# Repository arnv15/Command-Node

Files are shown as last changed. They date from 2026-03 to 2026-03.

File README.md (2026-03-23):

# Command Node

A fully custom 3D printed macropad built from scratch with a 3×3 key grid, rotary encoder, and OLED display.

## Features

- 9x Cherry MX switches in a 3×3 layout
- EC11 rotary encoder (volume control + OS toggle click)
- 0.91" 128×32 SSD1306 OLED display showing name and current OS layer
- Dual OS support — toggle between Windows and Mac layouts instantly
- KMK firmware written in CircuitPython (no compiling needed!)
- 3D printed case with heat-set inserts
- Seeed XIAO RP2040 microcontroller

## Overall Design

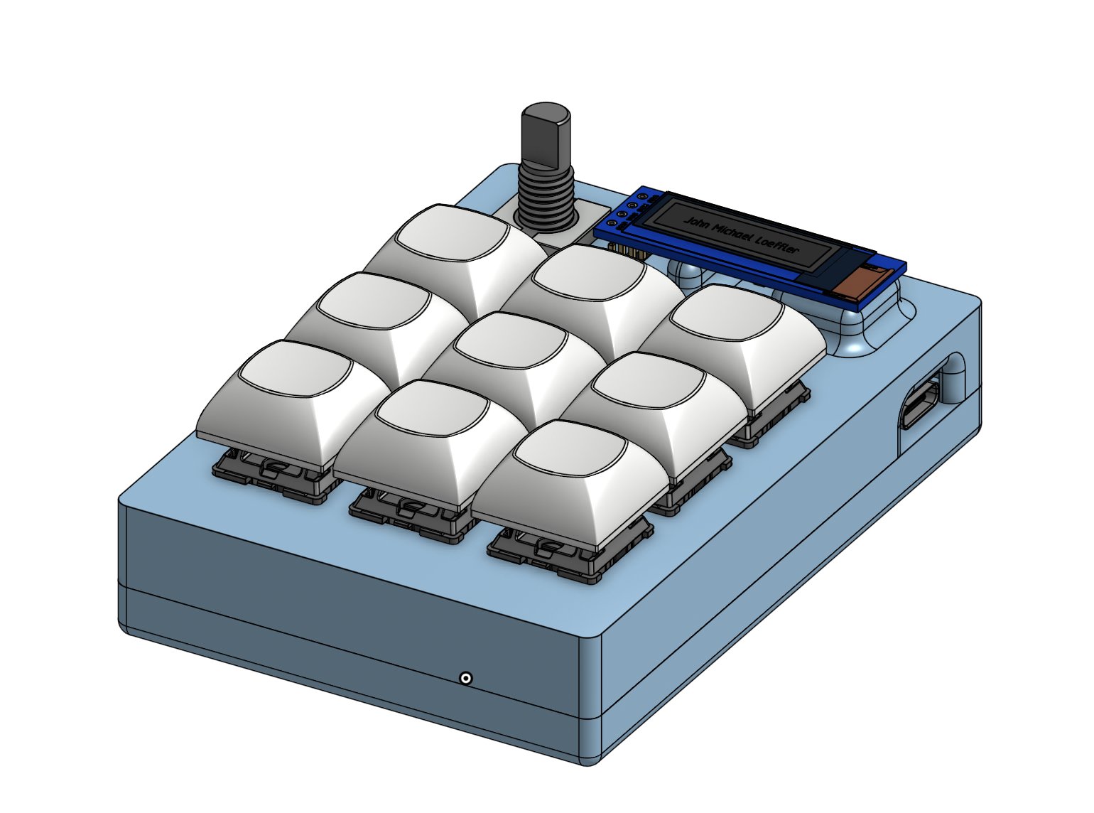
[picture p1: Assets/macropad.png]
Macropad render


The macropad features a compact 3×3 key layout with the rotary encoder and OLED display across the top. The USB-C port is accessible from the right side. The two-part 3D printed case is held together with M3 screws and heat-set inserts.

## PCB

| **Schematic** | **PCB Layout** |
| --- | --- |
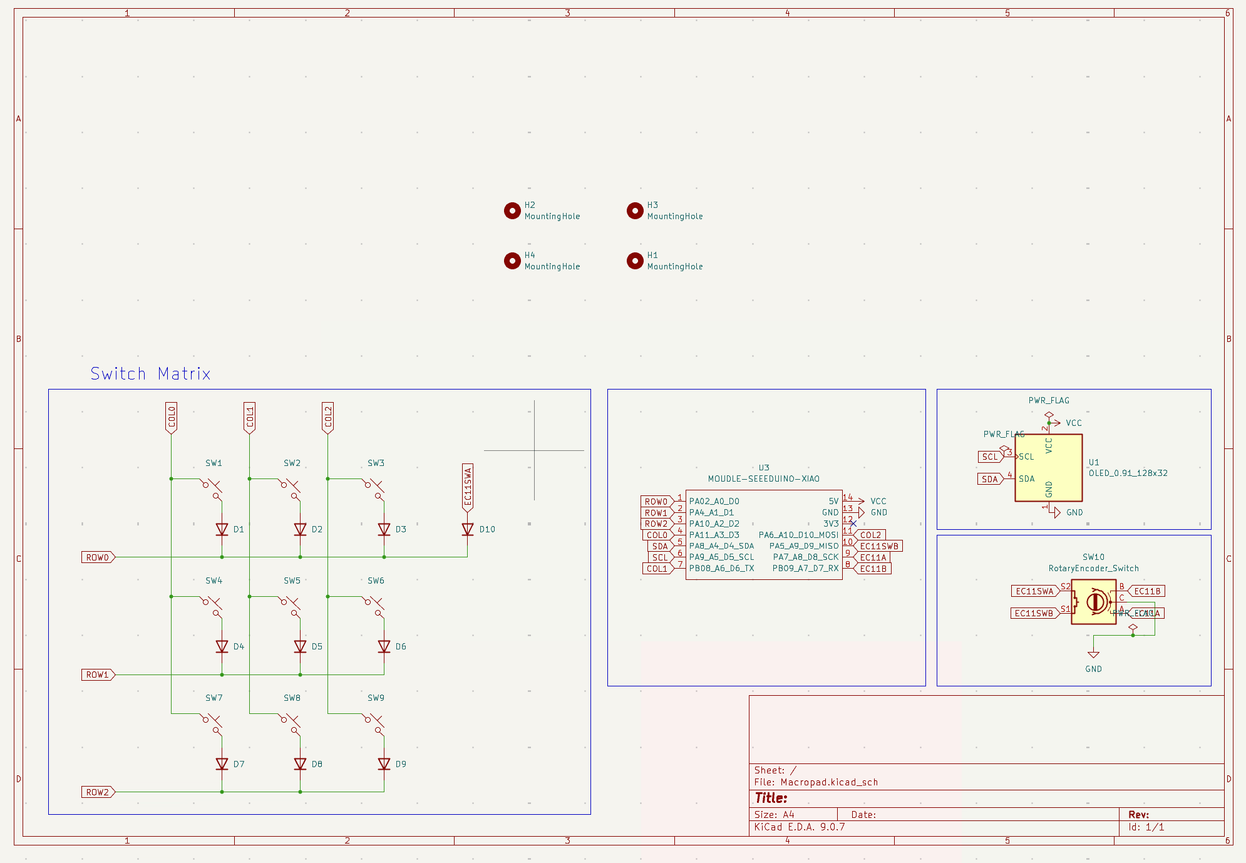
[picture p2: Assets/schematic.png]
Schematic
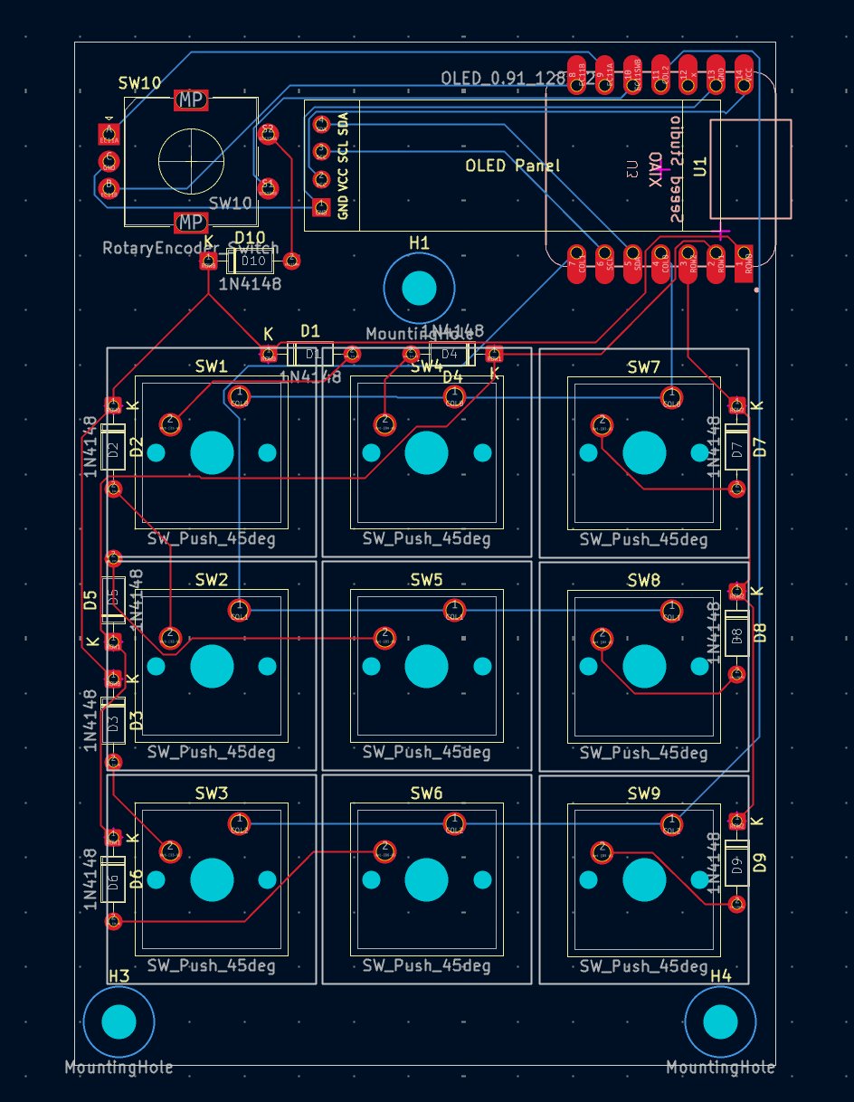
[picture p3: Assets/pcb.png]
PCB
|  |  |

The PCB was designed in KiCad. The switch matrix uses COL2ROW diode direction with 1N4148 diodes. The OLED connects via I2C on SDA/SCL pins, and the EC11 encoder click is wired as a direct pin (no diode needed).

- [x] I ran DRC and there are 0 errors

## CAD

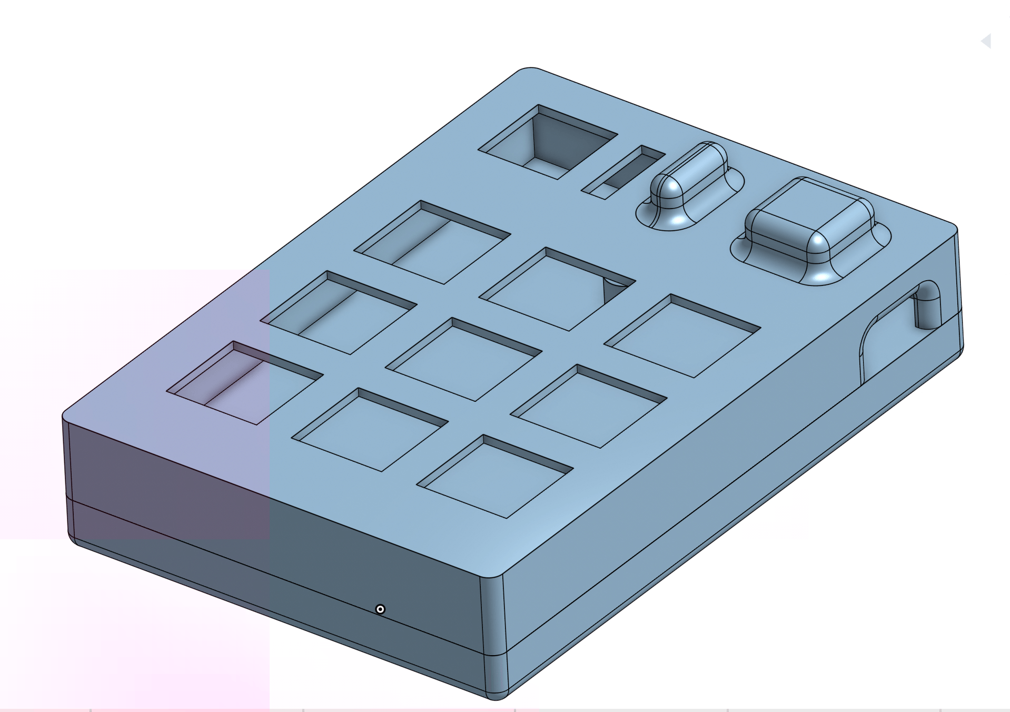
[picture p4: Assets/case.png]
Case assembly


The case is two-part and 3D printed. The top shell holds the switches, encoder, and OLED in place, while the bottom shell houses the PCB. Everything is secured with 4x M3x16mm screws threading into M3x5x4mm heat-set inserts pressed into the bottom shell.

[OnShape Link](https://cad.onshape.com/documents/35dce9458257a454ca9a87ec/w/10d574b05dc610b688c542cb/e/8b960576cf94807eaae72969)

## Firmware

Written using **KMK** (CircuitPython) — no compiling or flashing needed after the initial CircuitPython setup. Just edit `code.py` on the `CIRCUITPY` drive and it reloads automatically.

**Key layout:**

```
[ Prev  ] [ Play  ] [ Next  ]
[ Ctrl+Z] [ Ctrl+C] [ Ctrl+V]
[ Scrnsh] [ Sleep ] [ Scrnsvr]
         [Enc Click = OS Toggle]
```

**Encoder rotation:** Volume down / Volume up

**OS Toggle:** Pressing the encoder switches between Windows mode (Ctrl shortcuts, Print Screen) and Mac mode (Cmd shortcuts, Cmd+Shift+4 screenshot). The OLED updates to show the current OS.

**OLED display:** Shows name and current active OS layer dynamically.

You can find the full `main.py` in the `firmware/` folder of this repo.

## BOM

| Part | Quantity | Notes |
| --- | --- | --- |
| Seeed XIAO RP2040 | 1 | Microcontroller |
| Cherry MX Switches | 9 | Any MX-compatible switch |
| 1N4148 Diodes (through-hole) | 10 | 9 for switch matrix + 1 for encoder click |
| EC11 Rotary Encoder | 1 | With push-click |
| 0.91" SSD1306 OLED (128×32, I2C) | 1 | Pin order: GND-VCC-SCL-SDA |
| DSA Keycaps | 9 | White blank |
| M3x16mm Screws | 4 | For case assembly |
| M3x5x4mm Heat-set Inserts | 4 | Press into bottom shell |
| PCB | 1 | Custom KiCad design |
| 3D Printed Case (top + bottom) | 1 set | PLA or PETG |

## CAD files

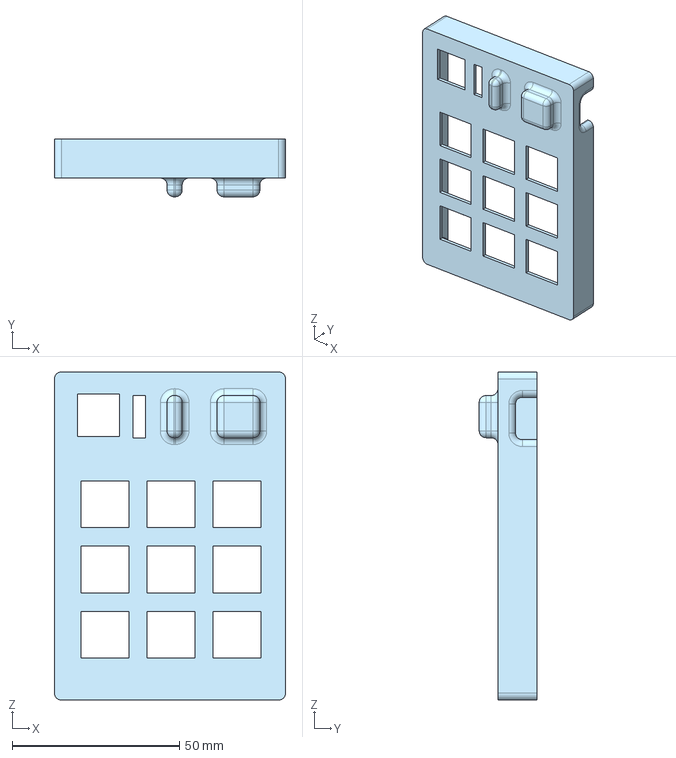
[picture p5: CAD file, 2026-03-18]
CAD/Top.step
69.1 x 17.2 x 98.1 mm

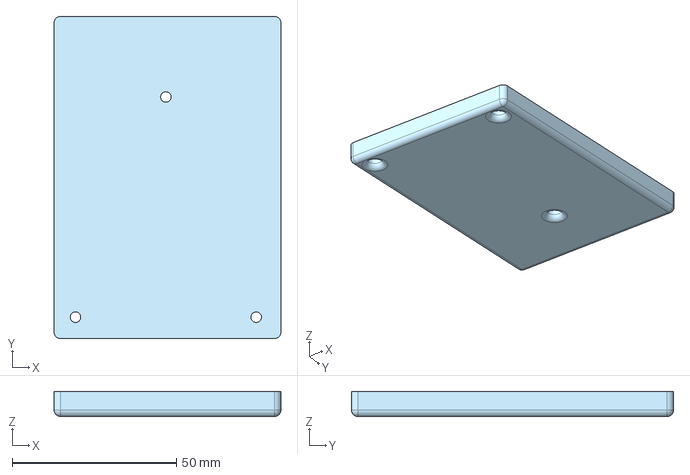
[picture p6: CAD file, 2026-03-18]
CAD/Bottom.step
69.1 x 98.1 x 7.62 mm

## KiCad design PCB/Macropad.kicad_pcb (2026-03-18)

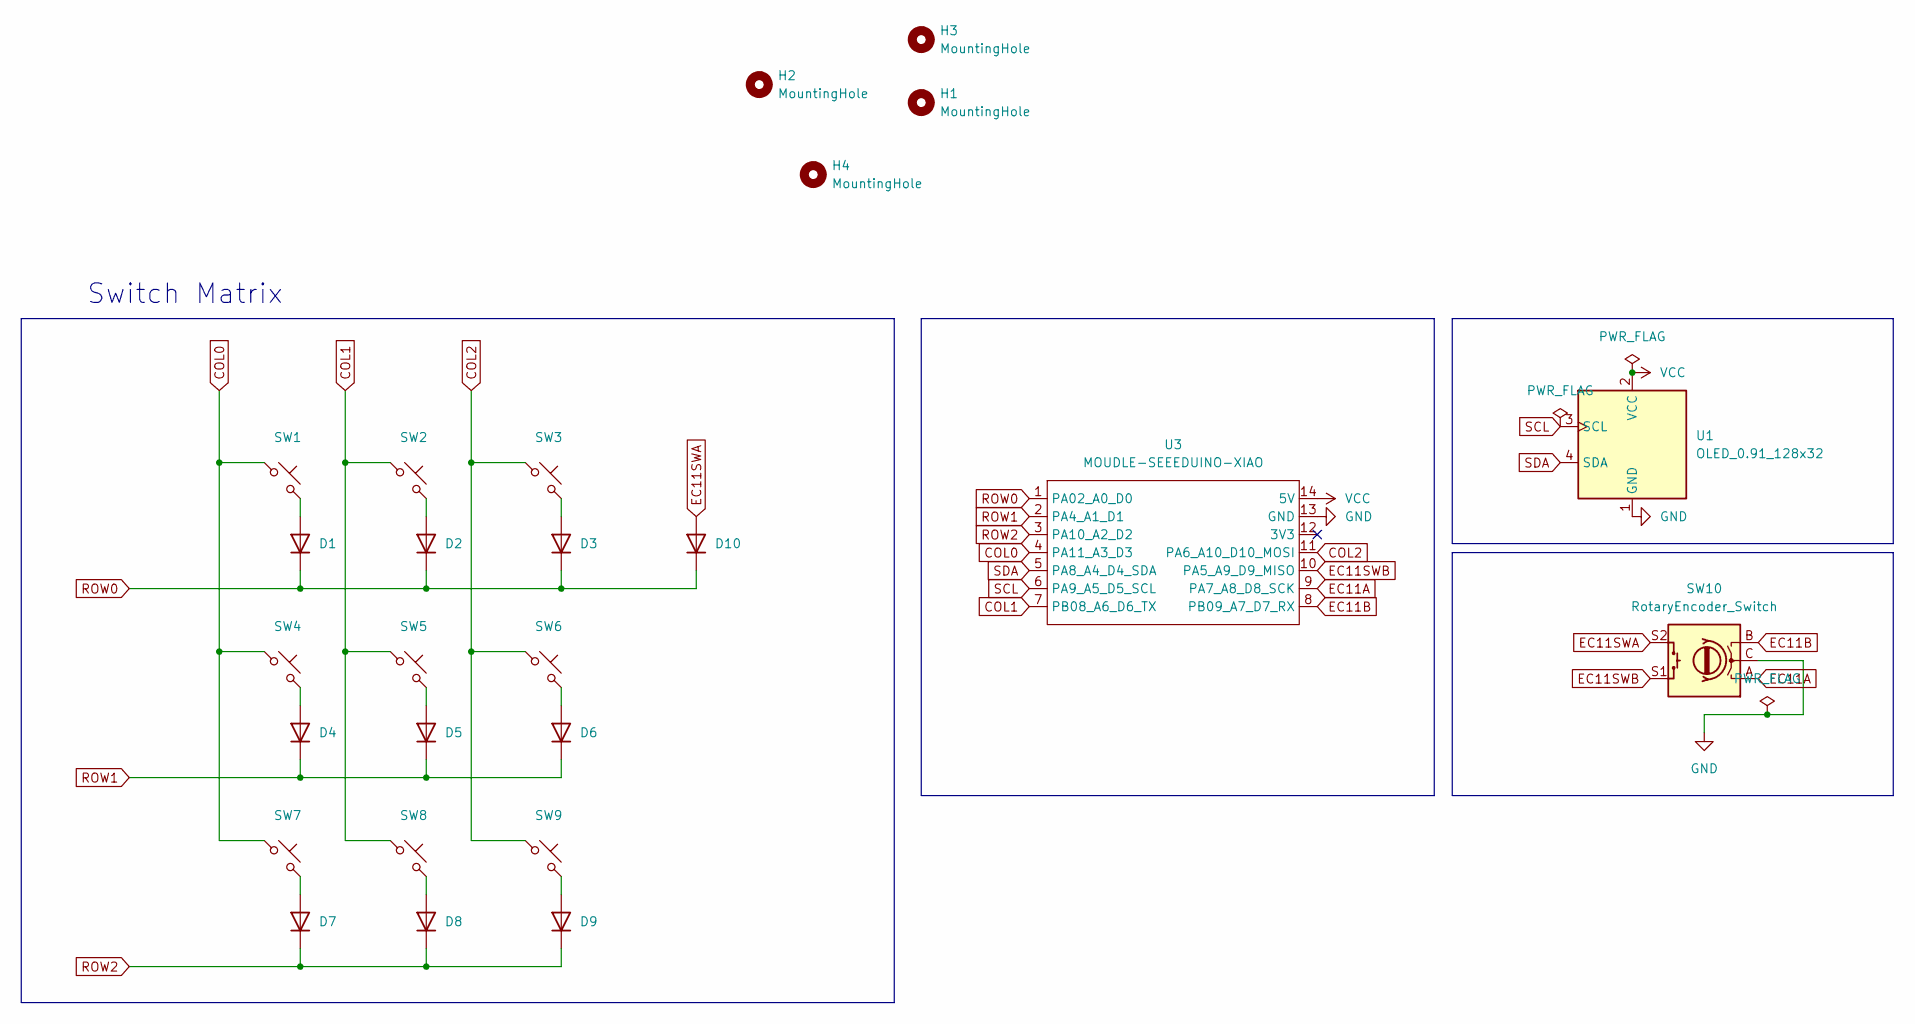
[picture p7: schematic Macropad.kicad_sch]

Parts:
D1, D2, D3, D4, D5, D6, D7, D8, D9, D10: 1N4148; D_DO-35_SOD27_P7.62mm_Horizontal
H1, H2, H3, H4: MountingHole; MountingHole_3.2mm_M3
SW1, SW2, SW3, SW4, SW5, SW6, SW7, SW8, SW9: SW_Push_45deg; SW_Cherry_MX_1.00u_PCB
SW10: RotaryEncoder_Switch; RotaryEncoder_Alps_EC11E-Switch_Vertical_H20mm
U1: OLED_0.91_128x32; SSD1306-0.91-OLED-4pin-128x32
U3: MOUDLE-SEEEDUINO-XIAO; XIAO-Generic-Hybrid-14P-2.54-21X17.8MM

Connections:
COL0: SW1.1, SW4.1, SW7.1, U3.4 (PA11_A3_D3)
COL1: SW2.1, SW5.1, SW8.1, U3.7 (PB08_A6_D6_TX)
COL2: SW3.1, SW6.1, SW9.1, U3.11 (PA6_A10_D10_MOSI)
EC11A: SW10.A, U3.9 (PA7_A8_D8_SCK)
EC11B: SW10.B, U3.8 (PB09_A7_D7_RX)
EC11SWA: D10.2 (A), SW10.S2
EC11SWB: SW10.S1, U3.10 (PA5_A9_D9_MISO)
GND: SW10.C, U1.1 (GND), U3.13 (GND)
unnamed: D1.2 (A), SW1.2
unnamed: D2.2 (A), SW2.2
unnamed: D3.2 (A), SW3.2
unnamed: D4.2 (A), SW4.2
unnamed: D5.2 (A), SW5.2
unnamed: D6.2 (A), SW6.2
unnamed: D7.2 (A), SW7.2
unnamed: D8.2 (A), SW8.2
unnamed: D9.2 (A), SW9.2
ROW0: D1.1 (K), D2.1 (K), D3.1 (K), D10.1 (K), U3.1 (PA02_A0_D0)
ROW1: D4.1 (K), D5.1 (K), D6.1 (K), U3.2 (PA4_A1_D1)
ROW2: D7.1 (K), D8.1 (K), D9.1 (K), U3.3 (PA10_A2_D2)
SCL: U1.3 (SCL), U3.6 (PA9_A5_D5_SCL)
SDA: U1.4 (SDA), U3.5 (PA8_A4_D4_SDA)
VCC: U1.2 (VCC), U3.14 (5V)

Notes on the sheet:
Switch Matrix

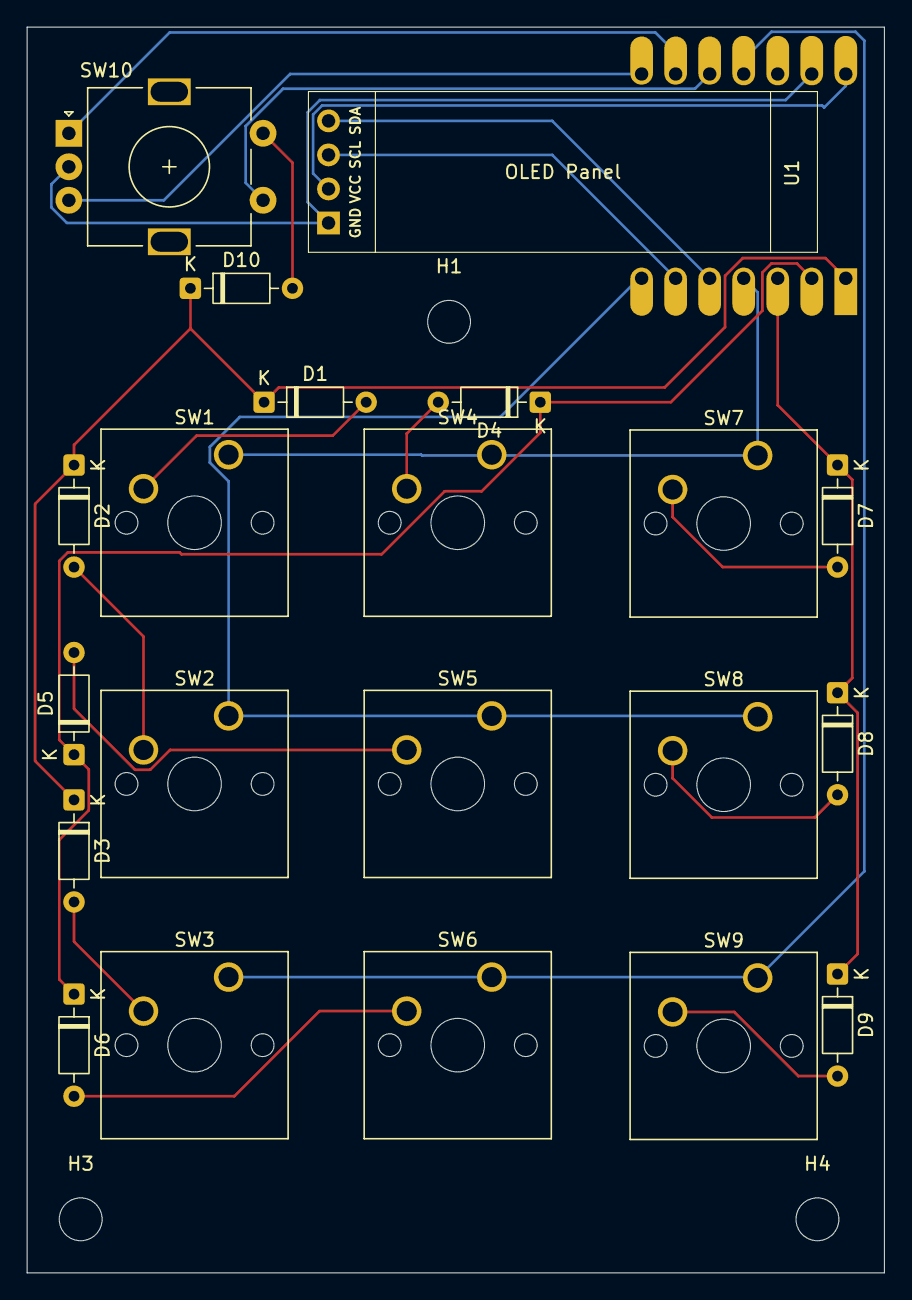
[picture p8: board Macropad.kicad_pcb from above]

Board: 2 copper layers, 64.0 x 93.0 mm, 25 parts (1 on the bottom side), 23 nets.

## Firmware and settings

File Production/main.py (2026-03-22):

import board
from kmk.kmk_keyboard import KMKKeyboard
from kmk.keys import KC
from kmk.modules.layers import Layers
from kmk.modules.encoder import EncoderHandler
from kmk.extensions.media_keys import MediaKeys
from kmk.extensions.oled import Oled, OledDisplayMode, OledReactionType
from kmk.hid import HIDModes
from kmk.scanners.keypad import MatrixScanner
from kmk.scanners.digitalio import KeysScanner

keyboard = KMKKeyboard()
keyboard.extensions.append(MediaKeys())
 
layers_ext = Layers()
keyboard.modules.append(layers_ext)

# MATRIX
keyboard.matrix = MatrixScanner(
    column_pins=(board.D3, board.D6, board.D10),  # COL0, COL1, COL2
    row_pins=(board.D0, board.D1, board.D2),       # ROW0, ROW1, ROW2
    columns_to_anodes=True,                         # COL2ROW diode direction
)

# ENCODER CLICK
encoder_click = KeysScanner(
    pins=(board.D9,),  # EC11SWA on GP4 = D9 on XIAO
)
keyboard.matrix = [keyboard.matrix, encoder_click]

# ENCODER ROTATION
encoder_handler = EncoderHandler()
encoder_handler.pins = ((board.D8, board.D7, None),)  # A=GP2, B=GP1, no push pin

encoder_handler.map = [
    ((KC.VOLD, KC.VOLU),),  # Windows
    ((KC.VOLD, KC.VOLU),),  # Mac
]
keyboard.modules.append(encoder_handler)


# Shortcut to toggle between layers
TOGGLE_OS = KC.TG(1)

keyboard.keymap = [

    # Windows
    [
        KC.MPRV,           KC.MPLY,           KC.MNXT,   
        KC.LCTL(KC.Z),     KC.LCTL(KC.C),     KC.LCTL(KC.V), 
        KC.PSCR,           KC.SLEP,           KC.SCRL,   
        TOGGLE_OS,                                   
    ],

    #Mac
    [
        KC.MPRV,                    KC.MPLY,              KC.MNXT,   
        KC.LGUI(KC.Z),              KC.LGUI(KC.C),        KC.LGUI(KC.V), 
        KC.LGUI(KC.LSFT(KC.N4)),    KC.SLEP,              KC.SCRL,   
        TOGGLE_OS,                                                   
    ],
]

# OLED DISPLAY
oled_ext = Oled(
    OledDisplayMode.TXT,
    toDisplay="Command Node",
    flip=False,
)
keyboard.extensions.append(oled_ext)

# START
if __name__ == '__main__':
    keyboard.run()

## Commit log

2026-03-18 Added CAD, PCB, Production files
    [Bottom.step, Macropad.kicad_pcb, Macropad.kicad_sch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]
2026-03-22 Fix images in README
    [main.py]
